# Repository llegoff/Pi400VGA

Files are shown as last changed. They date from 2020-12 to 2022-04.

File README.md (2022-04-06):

[:fr:](LISEZMOI.md) [:uk:](README.md)

# Pi400VGA
VGA interface for Raspberry Pi 400

:warning: for retrogaming on CRT see Scart/VGA interface : https://github.com/llegoff/Pi400RGB

for pi zero see https://github.com/llegoff/VGA_Zero

buy on [ebay](https://www.ebay.fr/itm/154872763613) :package:  

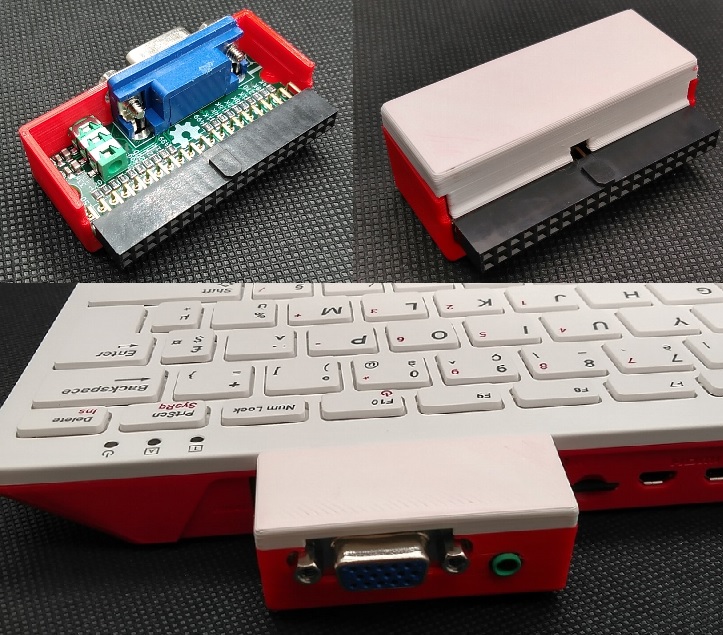
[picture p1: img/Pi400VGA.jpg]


### DPI (Display parallel Interface)
Like [VGA666](https://github.com/fenlogic/vga666), this pcb uses dpi interface (in mode 3 to free gpio 18 & 19)

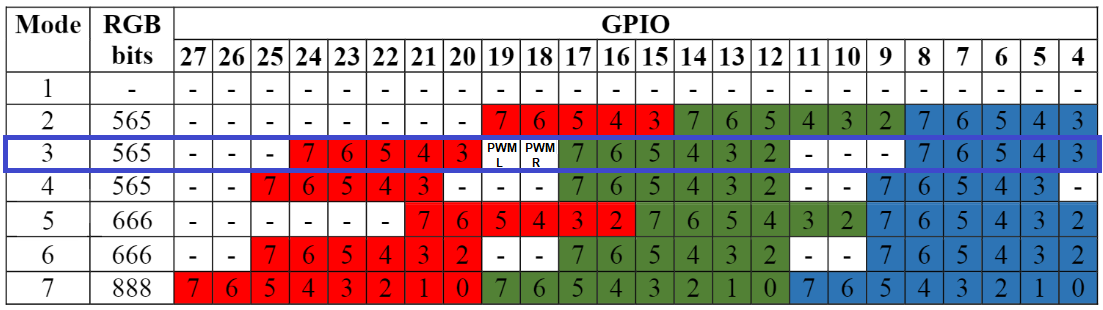
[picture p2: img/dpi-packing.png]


see https://www.raspberrypi.org/documentation/hardware/raspberrypi/dpi/README.md

only the necessary bits of the dpi are redirected to the 40-pin GPIO port, with the 'gpio=2-8,12-17,20-24=a2' line on config.txt

/boot/config.txt
    
    # disable i2c, pin use by h-sync & v-sync
    dtparam=i2c_arm=off
    # replace dtoverlay=vc4-kms-v3d with
    dtoverlay=vc4-fkms-v3d
    #DPI config
    gpio=2-8,12-17,20-24=a2
    dpi_output_format=0x13
    enable_dpi_lcd=1
    display_default_lcd=1
    dpi_group=2
    dpi_mode=16
    #---------------- dpi_mode line ---------------------
    #---> 640x480 60hz    dpi_mode=4
    #---> 800x600 60hz    dpi_mode=9
    #---> 1024x768 60hz   dpi_mode=16
    #---> 1280x768 60hz   dpi_mode=23
    #---> 1280x800 60hz   dpi_mode=28
    #---> 1280x960 60hz   dpi_mode=32
    #---> 1280x1024 60hz  dpi_mode=35
    #---> 1360x768 60hz   dpi_mode=39
    #---> 1366x768 60hz   dpi_mode=81
    #---> 1400x1050 60hz  dpi_mode=42
    #---> 1440x900 60hz   dpi_mode=47
    #---> 1600x1200 60hz  dpi_mode=51
    #---> 1680x1050 60hz  dpi_mode=58
    #---> 1920x1080 60hz  dpi_mode=82
    #---> 1920x1200 60hz  dpi_mode=69
    #---> 1920x1440 60hz  dpi_mode=73

Configuration working with vc4-kms-v3d

    dtoverlay=vc4-kms-dpi-generic,rgb565-padhi
    dtparam=hactive=800,hfp=40,hsync=128,hbp=88
    dtparam=vactive=600,vfp=1,vsync=4,vbp=23
    dtparam=clock-frequency=40000000
    #   Resolution@freq  hactive hfp hsync  hbp vactive vfp vsync vbp  clock-frequency
    #VGA   640x480  @60   640     16   96    48   480    10   2    33    25175000
    #SVGA  800x600  @60   800     40  128    88   600     1   4    23    40000000
    #XGA  1024x768  @60  1024     24  136   160   768     3   6    29    65000000
    #VESA 1368x768  @60  1368     72  144   216   768     1   3    23    85860000
    #VESA 1280x800  @60  1280     64  136   200   800     1   3    24    83460000
    #VESA 1280x1024 @60  1280     48  112   248  1024     1   3    38   108000000
    #VESA 1400x1050 @60  1400     88  152   240  1050     1   3    33   122660000
    #VESA 1600x1200 @60  1600     64  192   304  1200     1   3    46   162000000
    #--- TV -----
    #244p (NTSC res)@60   320      4   30    46   240     4   5    14     6400000
    #288p (PAL res) @50   384     16   32    40   288     3   2    19     7363200
    #480i (NTSC res)@60   640     24   64   104   480     3   6    34    13054080
    #576i (PAL res) @50   768     24   72    88   576     6   5    38    14875000
    #480p           @60   640     24   96    48   480    11   2    32    25452000
    #720p           @60  1280    110   40   220   720     5   5    20    74250000
    #1080p          @60  1920     88   44   148  1080     4   5    36   148500000
    #more timming on http://tinyvga.com/vga-timing

### 15khz cathode ray screen

:point_up: this config work only with Raspberry pi OS, not with Recalbox OS or RGB-Pi OS (use rpi-dpidac, who only work with dpi mode 5 & 6)

for RecalboxOS or RGB-Pi OG , see https://github.com/llegoff/Pi400RGB

    # replace dtoverlay=vc4-kms-v3d with
    dtoverlay=vc4-fkms-v3d
    # disable i2c, pin use by h-sync & v-sync
    dtparam=i2c_arm=off
    gpio=2-8,12-17,20-24=a2
    dpi_output_format=0x13
    enable_dpi_lcd=1
    display_default_lcd=1
    dpi_group=2
    dpi_mode=87
    #hdmi_timings=506 1 8 48 56 240 1 3 10 6 0 0 0 60 0 9600000 1
    #hdmi_timings=512 1 16 48 64 288 1 3 5 6 0 0 0 50 0 9600000 1
    # Custom 15kHz mode
    hdmi_timings=506 1 8 44 52 240 1 6 10 6 0 0 0 60 0 9600000 1
    #hdmi_timings=320 1 17 33 34 224 1 14 8 18 0 0 0 60 0 6400000 1
    #hdmi_timings=960 0 173 8 0 160 0 40 10 0 0 0 0 60 0 19200000 8
    #hdmi_timings=320 1 25 30 30 240 1 9 3 10 0 0 0 60 0 6400000 1
    #hdmi_timings=1920 1 52 208 260 240 1 6 10 6 0 0 0 60 0 38400000 1

### Recalbox

edit /boot/config.txt

find section 

    [pi4]
    temp_soft_limit=70
    dtoverlay=vc4-kms-v3d
    
remplace with

    [pi4]
    temp_soft_limit=70
    dtoverlay=vc4-fkms-v3d

copy content of [config-example.txt](img/config-example.txt?raw=true) to /boot/recalbox-user-config.txt
    
For crt mode , Recalbox 8 use driver rpi-dpidac, not compatible with dpi mode 3

see https://wiki.recalbox.com/en/tutorials/video/crt/crt-screen-dpi-vga666-piscart-rgbpi

### Dual Screen (VGA + HDMI)

on the pi4 and pi400, the dual screen function is supported by the vc4 fkms v3d driver

    [pi4]
    # Enable DRM VC4 V3D driver on top of the dispmanx display stack
    dtoverlay=vc4-fkms-v3d
    max_framebuffers=2

### Remote Desktop MultiMonitor
install freeRDP

    sudo apt-get install freerdp2-x11

start freeRDP session
    
    xfreerdp /v:<computer name or IP> /u:<user> /d:<domain> /sound:sys:alsa /multimon

or

    xfreerdp /v:<computer name or IP> /u:<user> /d:<domain> /g:<gateway name or IP> /gu:<gateway user> /gd:<gateway domain> /sound:sys:alsa /multimon

### Audio Interface
audio interface is connected to gpio 18 & 19 (PWM)

/boot/config.txt

    # Enable audio for PiZero(loads snd_bcm2835)
    dtoverlay=audremap,pins_18_19
    dtparam=audio=on

## Schematic
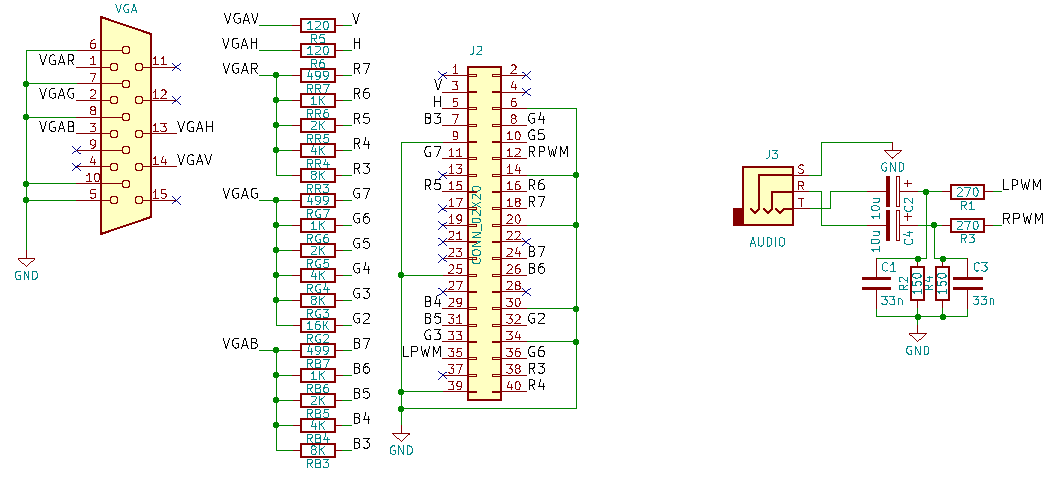
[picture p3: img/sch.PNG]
sch


## PCB
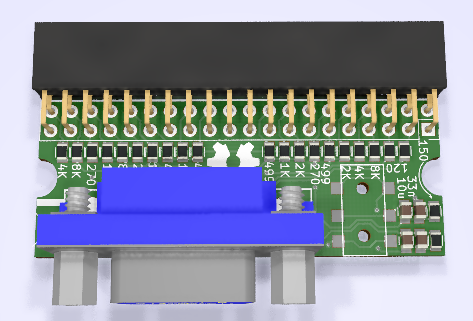
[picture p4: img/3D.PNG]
pcb


## Installation
copy content of [config-example.txt](img/config-example.txt?raw=true) to /boot/config.txt

## Révision
rev1

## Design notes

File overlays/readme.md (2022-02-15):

https://github.com/Cpasjuste/rpi-dpidac

https://www.higithub.com/rtomasa/repo/rpi-dpidac

https://gitlab.com/recalbox/recalbox/-/tree/master/projects/recalbox-rgb-dual

overlays for recalbox 8

recalbox 8 use driver rpi-dpidac

### patch recalbox 8

copy recalboxrgbdual.ko and recalboxrgbdual-thirdparty.dtbo in the overlays folder of the fat32 partition

copy Pi400VGA-config.txt in the crt/dacs folder of the fat32 partition

ssh recalbox

    cd /
    mount -o remount,rw /
    cd /lib/modules/5.10.83-v7l/extra/
    cp /boot/overlays/recalboxrgbdual.ko recalboxrgbdual.ko
    chmod 644 recalboxrgbdual.ko
    
reboot

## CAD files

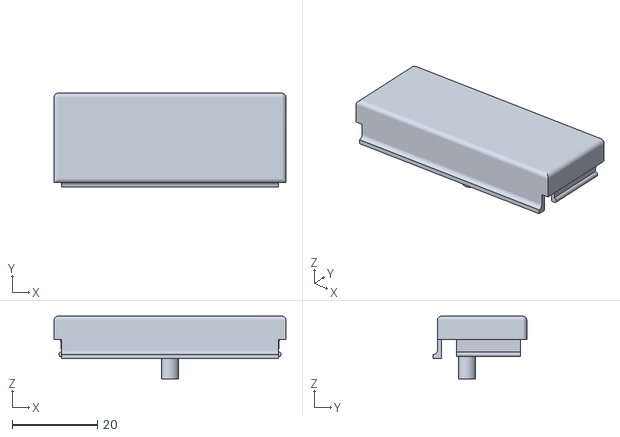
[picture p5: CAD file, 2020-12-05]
freecad/Top.stl
54.5 x 22.0 x 14.8

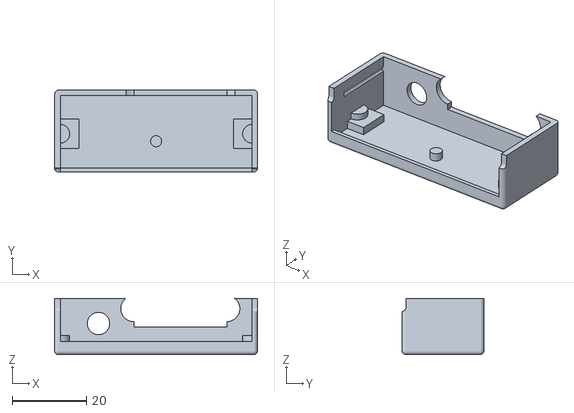
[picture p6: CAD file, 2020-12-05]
freecad/Bottom.stl
54.6 x 22.0 x 15.1

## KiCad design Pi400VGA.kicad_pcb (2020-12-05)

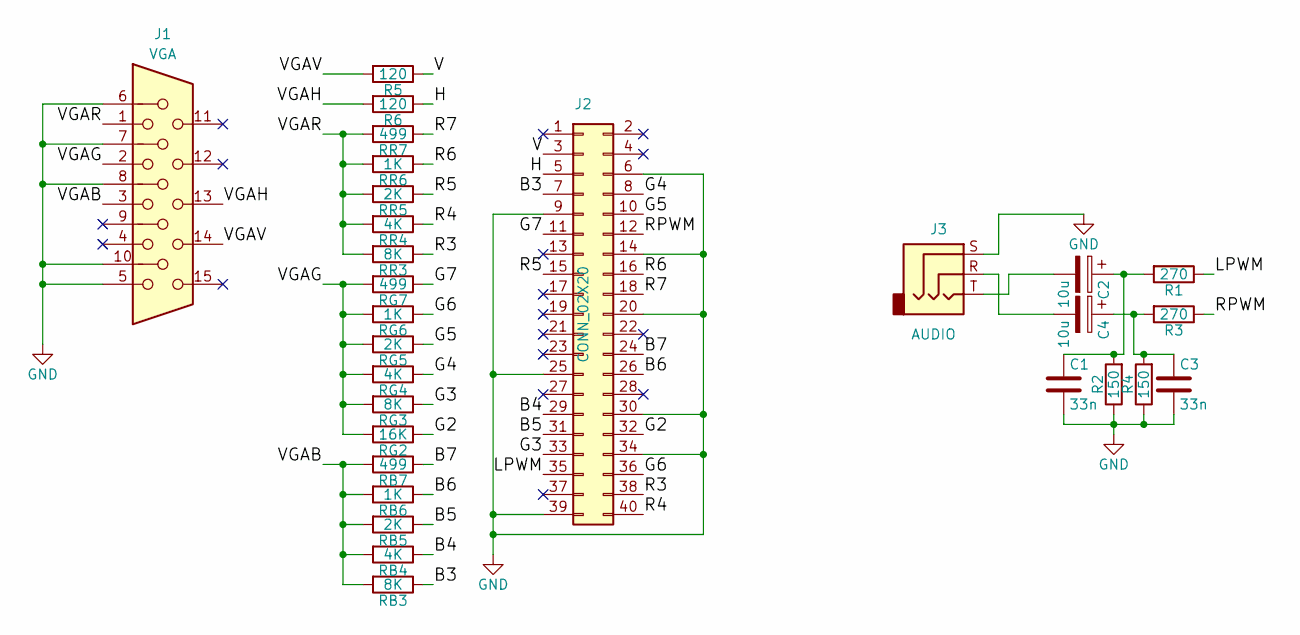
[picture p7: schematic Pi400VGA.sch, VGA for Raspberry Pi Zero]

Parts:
C1, C3: 33n; C_0805
C2, C4: 10u; C_0805
J1: VGA; DB_15F-VGA
J2: CONN_02X20; Socket_Strip_Straight_2x20_Pitch2.54mm
J3: AUDIO; jack3.5smd
R1, R3: 270; R_0805
R2, R4: 150; R_0805
R5, R6: 120; R_0805
RB3: 8K; R_0805
RB4: 4K; R_0805
RB5: 2K; R_0805
RB6: 1K; R_0805
RB7: 499; R_0805
RG2: 16K; R_0805
RG3: 8K; R_0805
RG4: 4K; R_0805
RG5: 2K; R_0805
RG6: 1K; R_0805
RG7: 499; R_0805
RR3: 8K; R_0805
RR4: 4K; R_0805
RR5: 2K; R_0805
RR6: 1K; R_0805
RR7: 499; R_0805

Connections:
/B3: J2.7, RB3.1
/B4: J2.29, RB4.1
/B5: J2.31, RB5.1
/B6: J2.26, RB6.1
/B7: J2.24, RB7.1
/G2: J2.32, RG2.1
/G3: J2.33, RG3.1
/G4: J2.8, RG4.1
/G5: J2.10, RG5.1
/G6: J2.36, RG6.1
/G7: J2.11, RG7.1
/H: J2.5, R6.1
/LPWM: J2.35, R1.1
/R3: J2.38, RR3.1
/R4: J2.40, RR4.1
/R5: J2.15, RR5.1
/R6: J2.16, RR6.1
/R7: J2.18, RR7.1
/RPWM: J2.12, R3.1
/V: J2.3, R5.1
/VGAB: J1.3, RB3.2, RB4.2, RB5.2, RB6.2, RB7.2
/VGAG: J1.2, RG2.2, RG3.2, RG4.2, RG5.2, RG6.2, RG7.2
/VGAH: J1.13, R6.2
/VGAR: J1.1, RR3.2, RR4.2, RR5.2, RR6.2, RR7.2
/VGAV: J1.14, R5.2
GND: C1.2, C3.2, J1.5, J1.6, J1.7, J1.8, J1.10, J2.6, J2.9, J2.14, J2.20, J2.25, J2.30, J2.34, J2.39, J3.S, R2.1, R4.1
unnamed: C1.1, C2.1, R1.2, R2.2
unnamed: C2.2, J3.T
unnamed: C3.1, C4.1, R3.2, R4.2
unnamed: C4.2, J3.R

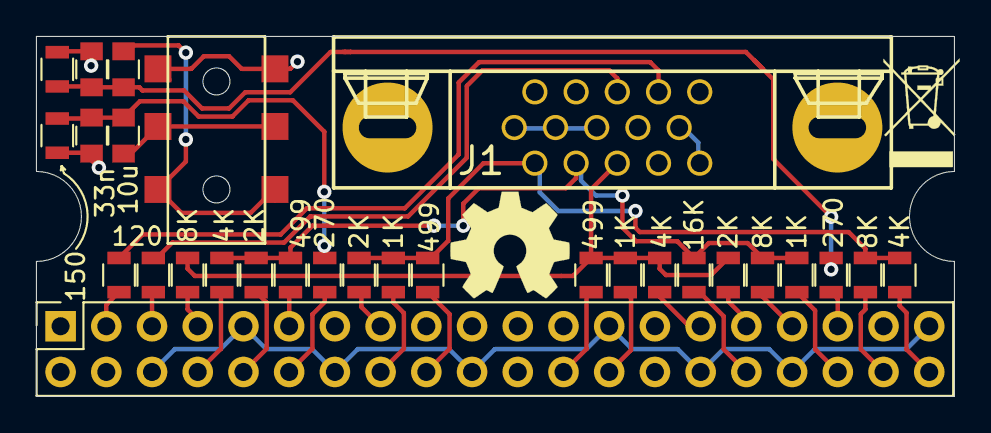
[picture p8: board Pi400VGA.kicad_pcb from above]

Board: 2 copper layers, 51.0 x 20.0 mm, 29 parts (0 on the bottom side), 30 nets.

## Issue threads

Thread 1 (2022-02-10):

Problème affichage

oct45, 2022-02-10:
J'ai un problème avec l'affichage, j'ai copié collé correctement l'exemple dans le config.txt, l'image s'affiche au démarrage (écran arc en ciel + le curseur clignote) puis plus aucun signal.

llegoff, 2022-02-10:
Bonsoir,
Sur quel OS ?  raspberry pi OS 32bits ou 64bits ? ou autre ?

oct45, 2022-02-11:
J'ai d'abord utilisé la version 64 bits puis la version 32 bits : sans succès

llegoff, 2022-02-11:
Bonjour,

je vois que dans la dernière version de raspberry pi OS, le pilote d'affichage KMS est chargé dans le config.txt , au lieu du FKMS auparavant

essayez en remplaçant les lignes

#Enable DRM vc4 V3D driver
dtoverlay=vc4-kms-v3d
maxframebuffer=2

par

#Enable DRM vc4 V3D driver
dtoverlay=vc4-fkms-v3d
maxframebuffer=2

oct45, 2022-02-12:
Cela a bien fonctionné merci, seul problème maintenant quand je mets la résolution de mon écran (1440x900) l'image est décalé à droite et semble écraser, dans des résolutions plus basses pas de soucis

llegoff, 2022-02-12:
Pour la résolution 1440x900, il faut la config suivante dans le fichier config.txt
dpi_group=2
dpi_mode=47

le port vga est un port analogique, les écran LCD effectuent une numérisation du signal, et effectuent une calibration pour détecter les limite de l'image, si la calibration automatique se fait lors du boot quand l'écran est noir, elle peut mal détecté les bord de l'image. il faut alors la relancer dans le menu de l'écran.

oct45, 2022-02-12:
J'utilise pourtant ces réglages et je refais manuellement la calibration de l'écran et rien n'y fait, il manque même des couleurs sur cette résolution (mon fond d'écran apparait en noir et blanc), avec le dpi_mode en 28 l'image est bonne pas de soucis, juste que tout est plus gros du coup

llegoff, 2022-02-12:
dpi_mode=48 pour la résolution 1440x900 à 75hz

oct45, 2022-02-14:
Avec le 46 au lieu du 47 ça fonctionne parfaitement encore merci

Closed 2022-02-14.

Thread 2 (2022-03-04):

Trying to work with RGB-Pi OS/4.  This config boots but the colors are off.  What changes need to be made?

RetroInVitro, 2022-03-04:
# Enable audio on GPIO for Pi400
#dtoverlay=audremap,pins_18_19 -----NO_DIFF?
dtoverlay=audremap,pins_18_19

dtparam=audio=on

# disable i2c, pin use by h-sync & v-sync
#dtparam=i2c_arm=off -----WORKED
#dtparam=i2c_arm=on -----BAD
dtparam=i2c_arm=off

# replace dtoverlay=vc4-kms-v3d with
#dtoverlay=vc4-fkms-v3d -----BAD
#dtoverlay=vc4-kms-v3d -----WORKED
dtoverlay=vc4-kms-v3d

#dtoverlay=vc4-vga666,mode6 -----WORKED
#dtoverlay=vc4-vga666-argon,mode6 -----WORKED but warning about legit
#dtoverlay=vc4-vga666-argon -----BAD
#dtoverlay=vc4-vga666,mode7 -----BAD_black screen
#dtoverlay=vc4-vga666,mode5 -----BAD_off colors and drops to cmd line
#dtoverlay=vc4-vga666,mode4 -----BAD_black screen
#dtoverlay=vc4-vga666,mode3 -----BAD_black screen
#dtoverlay=vc4-vga666,mode2 -----BAD_black screen
#dtoverlay=vc4-vga666,mode1 -----BAD_black screen
dtoverlay=vc4-vga666,mode6

#max_framebuffers=2 -----NO_DIFF?
max_framebuffers=2

#information https://www.raspberrypi.org/documentation/hardware/raspberrypi/dpi/README.md

gpio=0-1=a2
gpio=2-8,12-17,20-24=a2

#dpi_output_format=0x13 -----NO_DIFF?
#enable_dpi_lcd=1 -----NO_DIFF?
#display_default_lcd=1 -----NO_DIFF?

#dpi_output_format=0x13
#enable_dpi_lcd=1
#display_default_lcd=1

boot_delay=0
disable_splash=1
avoid_warnings=2
avoid_safe_mode=1
audio_pwm_mode=2
arm_boost=1
force_turbo=1
force_eeprom_read=0

#dpi_group=2
#dpi_mode=87
#hdmi_timings=320 1 25 30 30 240 1 9 3 10 0 0 0 60 0 6400000 1

#dpi_group=2
#dpi_mode=16
#---------------- dpi_mode line ---------------------
#---> 640x480 60hz   dpi_mode=4
#---> 800x600 60hz   dpi_mode=9
#---> 1024x768 60hz  dpi_mode=16
#---> 1280x768 60hz  dpi_mode=23
#---> 1280x800 60hz  dpi_mode=28
#---> 1280x960 60hz  dpi_mode=32
#---> 1280x1024 60hz dpi_mode=35
#---> 1360x768 60hz  dpi_mode=39
#---> 1366x768 60hz  dpi_mode=81
#---> 1400x1050 60hz dpi_mode=42
#---> 1440x900 60hz  dpi_mode=47
#---> 1600x1200 60hz dpi_mode=51
#---> 1680x1050 60hz dpi_mode=58
#---> 1920x1080 60hz dpi_mode=82
#---> 1920x1200 60hz dpi_mode=69
#---> 1920x1440 60hz dpi_mode=73

RetroInVitro, 2022-03-19:
Per llegoff in an offline chat, it turns out that Pi400VGA isn't compatible with some GPIO mappings for various configs like RGB-Pi OS/4.  Instead use his other adapter Pi400RGB.

RetroInVitro, 2022-03-19:
Working config.txt for RGB-Pi OS/4 (as of v9 20220219) with Pi400RGB:

--------------------

# Enable audio on GPIO for Pi400
dtoverlay=audremap,pins_18_19

dtparam=audio=on

# disable i2c, pin use by h-sync & v-sync
dtparam=i2c_arm=off

# replace dtoverlay=vc4-kms-v3d with
dtoverlay=vc4-kms-v3d
dtoverlay=vc4-vga666,mode6

#max_framebuffers=2 -----NO_DIFF?
max_framebuffers=2

#information https://www.raspberrypi.org/documentation/hardware/raspberrypi/dpi/README.md

gpio=0-1=a2
gpio=2-8,12-17,20-24=a2

boot_delay=0
disable_splash=1
avoid_warnings=2
avoid_safe_mode=1
audio_pwm_mode=2
arm_boost=1
force_turbo=1
force_eeprom_read=0

Closed 2022-03-19.

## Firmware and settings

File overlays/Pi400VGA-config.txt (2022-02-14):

#device=Pi400VGA
dtoverlay=recalboxrgbdual-thirdparty,mode3
audio_pwm_mode=2
dtoverlay=audremap,pins_18_19

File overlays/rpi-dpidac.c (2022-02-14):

/*
 * Copyright (C) 2018 Hugh Cole-Baker
 *
 * Hugh Cole-Baker <sigmaris@gmail.com>
 *
 * This program is free software; you can redistribute it and/or
 * modify it under the terms of the GNU General Public License as
 * published by the Free Software Foundation; either version 2 of
 * the License, or (at your option) any later version.
 */

#include <linux/module.h>
#include <linux/platform_device.h>

#include <video/display_timing.h>
#include <video/of_display_timing.h>
#include <video/videomode.h>

#include <drm/drm_atomic_helper.h>
#include <drm/drm_bridge.h>
#include <drm/drm_crtc.h>
#include <drm/drm_crtc_helper.h>
#include <drm/drm_mipi_dsi.h>
#include <drm/drm_print.h>
#include <drm/drm_probe_helper.h>

// ~ 20 timings line + comments
#define READ_SIZE_MAX 2048
#define LINE_SIZE_MAX 256

static char read_buf[READ_SIZE_MAX];
static const char *timings_path = "/boot/timings.txt";

static struct drm_display_mode *dpidac_display_mode_from_timings(struct drm_connector *connector, const char *line) {
    int ret, hsync, vsync, interlace, ratio;
    struct drm_display_mode *mode = NULL;
    struct videomode vm;

    if (line != NULL) {
        memset(&vm, 0, sizeof(vm));
        ret = sscanf(line, "%d %d %d %d %d %d %d %d %d %d %*s %*s %*s %*s %d %ld %d",
                     &vm.hactive, &hsync, &vm.hfront_porch, &vm.hsync_len, &vm.hback_porch,
                     &vm.vactive, &vsync, &vm.vfront_porch, &vm.vsync_len, &vm.vback_porch,
                     &interlace, &vm.pixelclock, &ratio);
        if (ret != 13) {
            printk(KERN_WARNING "[RPI-DPIDAC]: malformed mode requested, skipping (%s)\n", line);
            return NULL;
        }

        // setup flags
        vm.flags = interlace ? DISPLAY_FLAGS_INTERLACED : 0;
        vm.flags |= hsync ? DISPLAY_FLAGS_HSYNC_LOW : DISPLAY_FLAGS_HSYNC_HIGH;
        vm.flags |= vsync ? DISPLAY_FLAGS_VSYNC_LOW : DISPLAY_FLAGS_VSYNC_HIGH;

        // create/init display mode, convert from video mode
        mode = drm_mode_create(connector->dev);
        if (mode == NULL) {
            printk(KERN_WARNING "[RPI-DPIDAC]: drm_mode_create failed, skipping (%s)\n", line);
            return NULL;
        }

        drm_display_mode_from_videomode(&vm, mode);

        return mode;
    }

    return NULL;
}

int dpidac_load_timings(struct drm_connector *connector) {
    struct file *fp = NULL;
    ssize_t read_size = 0;
    size_t cursor = 0;
    char line[LINE_SIZE_MAX];
    size_t line_start = 0;
    size_t line_len = 0;
    struct drm_display_mode *mode = NULL;
    int mode_count = 0;

    fp = filp_open(timings_path, O_RDONLY, 0);
    if (IS_ERR(fp) || !fp) {
        printk(KERN_WARNING "[RPI-DPIDAC]: timings file not found, skipping custom modes loading\n");
        return 0;
    }

    read_size = kernel_read(fp, &read_buf, READ_SIZE_MAX, &fp->f_pos);
    if (read_size <= 0) {
        filp_close(fp, NULL);
        printk(KERN_WARNING "[RPI-DPIDAC]: empty timings file found, skipping custom modes loading\n");
        return 0;
    }
    filp_close(fp, NULL);

    for (cursor = 0; cursor < read_size; cursor++) {
        line[cursor - line_start] = read_buf[cursor];
        line_len++;
        if (line_len >= LINE_SIZE_MAX || read_buf[cursor] == '\n' || read_buf[cursor] == '\0') {
            if (line_len > 32 && line[0] != '#') {
                line[line_len - 1] = '\0';
                if ((mode = dpidac_display_mode_from_timings(connector, line)) != NULL) {
                    mode->type = mode_count ? DRM_MODE_TYPE_DRIVER : DRM_MODE_TYPE_DRIVER | DRM_MODE_TYPE_PREFERRED;
                    //printk(KERN_INFO "[RPI-DPIDAC]: \t" DRM_MODE_FMT, DRM_MODE_ARG(mode));
                    drm_mode_probed_add(connector, mode);
                    mode_count++;
                }
            }
            line_start += line_len;
            line_len = 0;
            memset(line, 0, 128);
        }
    }

    return mode_count;
}

struct dpidac {
    struct drm_bridge bridge;
    struct drm_connector connector;
    struct display_timings *timings;
};

static inline struct dpidac *drm_bridge_to_dpidac(struct drm_bridge *bridge) {
    return container_of(bridge, struct dpidac, bridge);
}

static inline struct dpidac *drm_connector_to_dpidac(struct drm_connector *connector) {
    return container_of(connector, struct dpidac, connector);
}

static int dpidac_get_modes(struct drm_connector *connector) {
    struct drm_device *dev = connector->dev;
    struct dpidac *vga = drm_connector_to_dpidac(connector);
    struct display_timings *timings = vga->timings;
    int i;

    i = dpidac_load_timings(connector);
    if (i) {
        //printk(KERN_INFO "[RPI-DPIDAC]: dpidac_get_modes: %i custom modes loaded\n", i);
        return i;
    } else if (timings) {
        for (i = 0; i < timings->num_timings; i++) {
            struct drm_display_mode *mode = drm_mode_create(dev);
            struct videomode vm;

            if (videomode_from_timings(timings, &vm, i))
                break;

            drm_display_mode_from_videomode(&vm, mode);

            mode->type = DRM_MODE_TYPE_DRIVER;

            if (timings->native_mode == i)
                mode->type |= DRM_MODE_TYPE_PREFERRED;

            drm_mode_set_name(mode);
            drm_mode_probed_add(connector, mode);
        }
        //printk(KERN_INFO "[RPI-DPIDAC]: dpidac_get_modes: %i modes loaded from dtb overlay\n", i);
    } else {
        /* Since there is no timing data, use XGA standard modes */
        i = drm_add_modes_noedid(connector, 1920, 1200);
        /* And prefer a mode pretty much anyone can handle */
        drm_set_preferred_mode(connector, 1024, 768);
        //printk(KERN_INFO "[RPI-DPIDAC]: dpidac_get_modes: fallback to XGA mode...\n");
    }

    return i;
}

static const struct drm_connector_helper_funcs dpidac_con_helper_funcs = {
        .get_modes    = dpidac_get_modes,
};

static enum drm_connector_status dpidac_connector_detect(struct drm_connector *connector, bool force) {
    return connector_status_connected;
}

static const struct drm_connector_funcs dpidac_con_funcs = {
        .detect            = dpidac_connector_detect,
        .fill_modes        = drm_helper_probe_single_connector_modes,
        .destroy        = drm_connector_cleanup,
        .reset            = drm_atomic_helper_connector_reset,
        .atomic_duplicate_state    = drm_atomic_helper_connector_duplicate_state,
        .atomic_destroy_state    = drm_atomic_helper_connector_destroy_state,
};
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
